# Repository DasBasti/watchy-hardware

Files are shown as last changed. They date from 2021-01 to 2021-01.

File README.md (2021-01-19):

# Schmartwatch 2.0 (fork watchy-hardware)
Modified Watchy Hardware CAD Files

Changes to original Watchy:
* DCDC switch mode power supply
* RV-3028-C7 RTC
* supporting 3-color e-Paper display

OSHWA US000936 (https://certification.oshwa.org/us000936.html)

Read the docs at [https://watchy.sqfmi.com/](https://watchy.sqfmi.com/)
More information at [http://schmartwatch.com](http://schmartwatch.com/)

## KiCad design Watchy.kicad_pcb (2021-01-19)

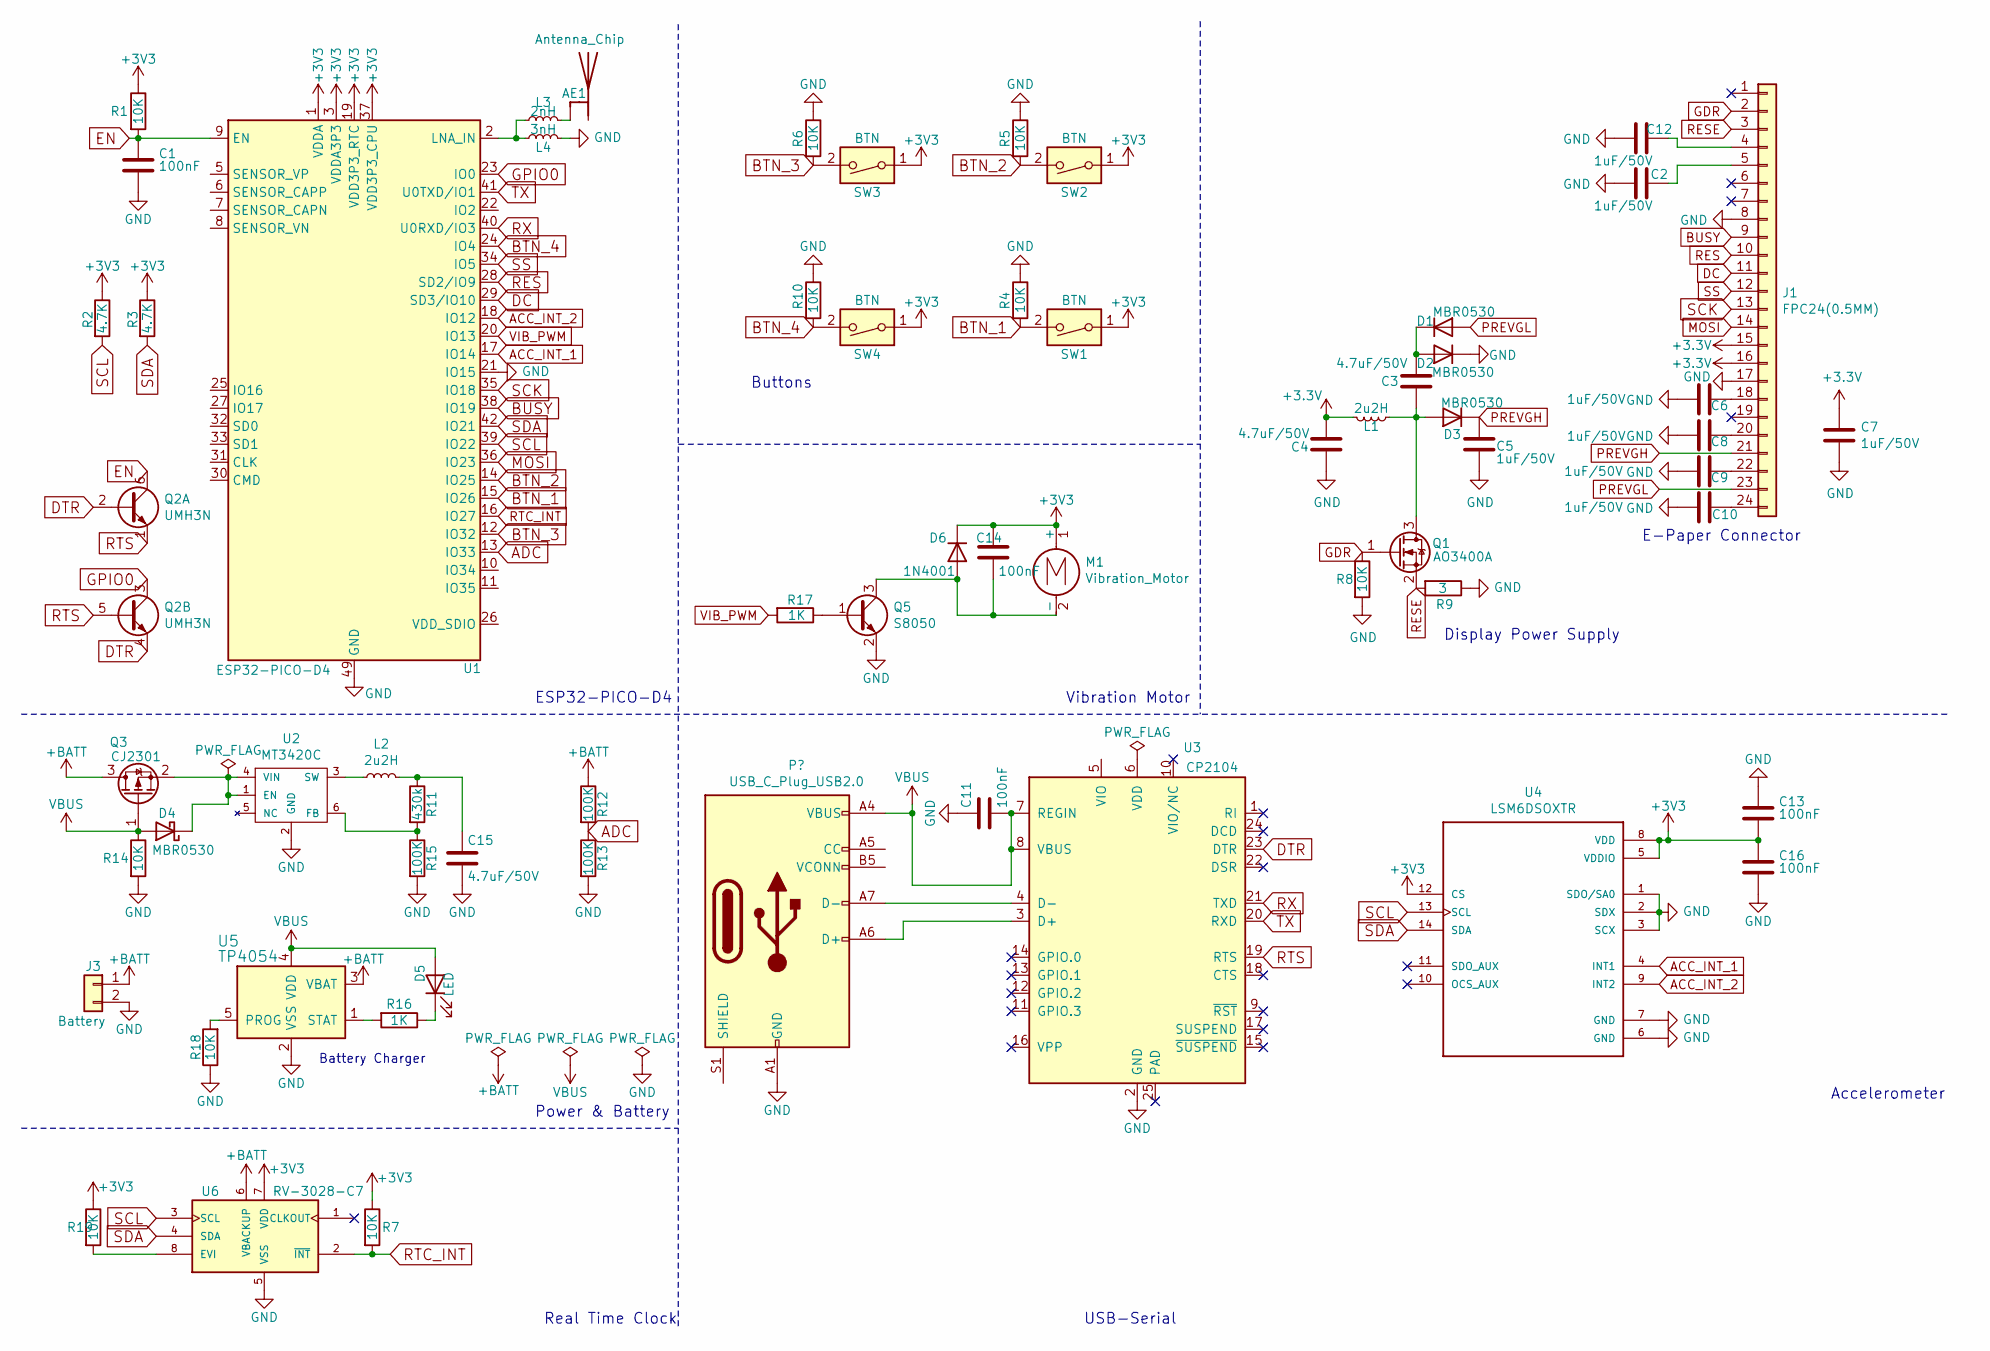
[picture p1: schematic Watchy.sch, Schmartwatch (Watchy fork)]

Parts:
AE1: Antenna_Chip; ANT_ANT016008LCS2442MA2
C1, C11, C13, C14, C16: 100nF; C_0603_1608Metric
C2, C5, C6, C7, C8, C9, C10, C12: 1uF/50V; C_0603_1608Metric
C3, C4, C15: 4.7uF/50V; C_0805_2012Metric
D1, D2, D3, D4: MBR0530; D_SOD-123
D5: LED; LED_0603_1608Metric
D6: 1N4001; D_SOD-123F
J1: FPC24(0.5MM); 24_Pins_0.5mm_Pitch_ZIF_Connector_UP
J3: Battery; 1.25T-2PWT (Molex 532610271)
L1, L2: 2u2H; L_0603_1608Metric; MPN KPS0603LD2R2KST
L3: 2nH; L_0402_1005Metric; MPN SWPA252012S2R2MT
L4: 3nH; L_0402_1005Metric; MPN SWPA252012S2R2MT
M1: Vibration_Motor; Motor_Header; MPN C1026B002F
Q1: AO3400A; SOT-23
Q2: UMH3N; SOT-363_SC-70-6
Q3: CJ2301; SOT-23
Q5: S8050; SOT-23
R1, R4, R5, R6, R7, R8, R10, R14, R18, R19: 10K; R_0402_1005Metric
R2, R3: 4.7K; R_0402_1005Metric
R9: 3; R_0402_1005Metric
R11: 430k; R_0402_1005Metric; MPN 0402WGF4303TCE
R12, R13, R15: 100K; R_0402_1005Metric
R16, R17: 1K; R_0402_1005Metric
SW1, SW2, SW3, SW4: BTN; K2-1114SA-A4SW-06
U1: ESP32-PICO-D4; QFN-48-1EP_7x7mm_P0.5mm_EP5.45x5.45mm
U2: MT3420C; SOT-23-6; MPN MT3420C; LCSC_PN C181741
U3: CP2104; QFN-24-1EP_4x4mm_Pitch0.5mm
U4: LSM6DSOXTR; PQFN50P250X300X86-14N
U5: TP4054; SOT-23-5
U6: RV-3028-C7; IC_RV-3028-C7; PARTREV 1.1

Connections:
+BATT: J3.1, Q3.3 (D), R12.1, U5.3 (VBAT), U6.6 (VBACKUP)
ACC_INT_1: U1.17 (IO14), U4.4 (INT1)
ACC_INT_2: U1.18 (IO12), U4.9 (INT2)
ADC: R12.2, R13.1, U1.13 (IO33)
BTN_1: R4.2, SW1.2, U1.15 (IO26)
BTN_2: R5.2, SW2.2, U1.14 (IO25)
BTN_3: R6.2, SW3.2, U1.12 (IO32)
BTN_4: R10.2, SW4.2, U1.24 (IO4)
BUSY: J1.9, U1.38 (IO19)
DC: J1.11, U1.29 (SD3/IO10)
DTR: Q2.2 (B1), Q2.4 (E2), U3.23 (DTR)
EN: C1.1, Q2.6 (C1), R1.2, U1.9 (EN)
GDR: J1.2, Q1.1 (G), R8.1
GND: C1.2, C2.2, C4.2, C5.2, C6.2, C7.2, C8.2, C9.2, C10.2, C11.1, C12.2, C13.1, C15.2, C16.2, D2.1 (K), J1.8, J1.17, J3.2, L4.2, Q5.2 (E), R4.1, R5.1, R6.1, R8.2, R9.1, R10.1, R13.2, R14.2, R15.2, R18.1, U1.21 (IO15), U1.49 (GND), U2.2 (GND), U3.2 (GND), U4.1 (SDO/SA0), U4.2 (SDX), U4.3 (SCX), U4.6 (GND), U4.7 (GND), U5.2 (VSS), U6.5 (VSS)
GPIO0: Q2.3 (C2), U1.23 (IO0)
MOSI: J1.14, U1.36 (IO23)
unnamed: AE1.4 (FEED), L3.2
unnamed: C2.1, J1.5
unnamed: C3.1, D1.1 (K), D2.2 (A)
unnamed: C3.2, D3.2 (A), L1.1, Q1.3 (D)
unnamed: C6.1, J1.18
unnamed: C8.1, J1.20
unnamed: C9.1, J1.22
unnamed: C10.1, J1.24
unnamed: C12.1, J1.4
unnamed: C14.2, D6.2 (A), M1.2 (-), Q5.3 (C)
unnamed: C15.1, L2.2, R11.1
unnamed: D4.1 (K), Q3.2 (S), U2.1 (EN), U2.4 (VIN)
unnamed: D5.1 (K), R16.1
unnamed: L2.1, U2.3 (SW)
unnamed: L3.1, L4.1, U1.2 (LNA_IN)
unnamed: Q5.1 (B), R17.1
unnamed: R11.2, R15.1, U2.6 (FB)
unnamed: R16.2, U5.1 (STAT)
unnamed: R18.2, U5.5 (PROG)
unnamed: R19.2, U6.8 (EVI)
PREVGH: C5.1, D3.1 (K), J1.21
PREVGL: D1.2 (A), J1.23
RES: J1.10, U1.28 (SD2/IO9)
RESE: J1.3, Q1.2 (S), R9.2
RTC_INT: R7.2, U1.16 (IO27), U6.2 (~INT)
RTS: Q2.1 (E1), Q2.5 (B2), U3.19 (RTS)
RX: U1.40 (U0RXD/IO3), U3.21 (TXD)
SCK: J1.13, U1.35 (IO18)
SCL: R2.2, U1.39 (IO22), U4.13 (SCL), U6.3 (SCL)
SDA: R3.2, U1.42 (IO21), U4.14 (SDA), U6.4 (SDA)
SS: J1.12, U1.34 (IO5)
TX: U1.41 (U0TXD/IO1), U3.20 (RXD)
VBUS: C11.2, D4.2 (A), D5.2 (A), Q3.1 (G), R14.1, U3.7 (REGIN), U3.8 (VBUS), U5.4 (VDD)
VIB_PWM: R17.2, U1.20 (IO13)

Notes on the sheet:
ESP32-PICO-D4
Power & Battery
Real Time Clock
USB-Serial
Accelerometer
E-Paper Connector
Buttons
Vibration Motor
Battery Charger
Display Power Supply

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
Board: 2 copper layers, 63 parts (0 on the bottom side), 51 nets, no tracks yet.
